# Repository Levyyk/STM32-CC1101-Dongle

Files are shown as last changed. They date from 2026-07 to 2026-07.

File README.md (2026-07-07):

# STM32 CC1101 USB Dongle

Custom USB dongle design featuring **STM32F030F4P6** + **CC1101** RF transceiver + **CH340N** USB-UART bridge.
A complete schematic and PCB design project built in Altium Designer — from component selection to a production-ready layout.

> **Note:** This is a design-stage project — the board has not been manufactured/assembled. The repository showcases the schematic and PCB design process rather than a physical build or firmware implementation.

| Front (3D) | Back (3D) |
|---|---|
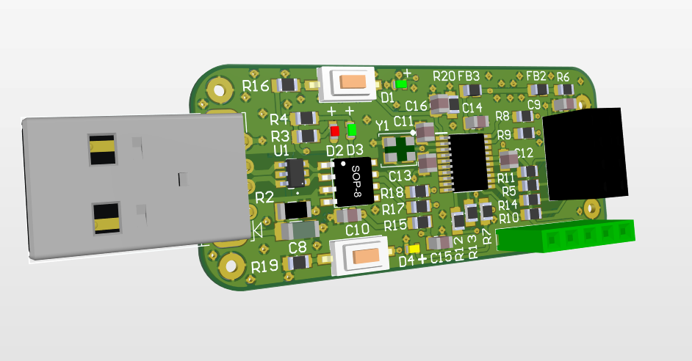
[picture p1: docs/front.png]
Board front
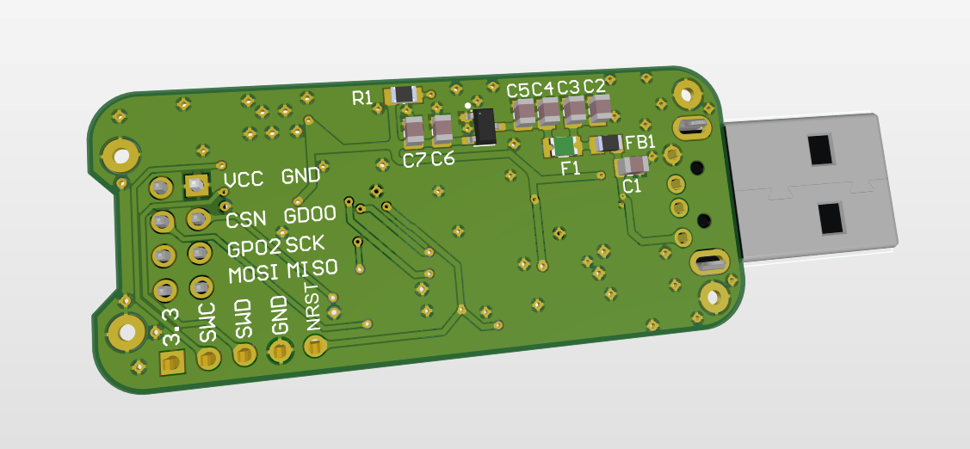
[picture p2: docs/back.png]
Board back
|  |  |

---

## Overview

This project is a compact USB dongle designed for interfacing with sub-GHz RF devices via the CC1101 transceiver. The STM32F030F4P6 is intended to handle SPI communication with the CC1101 and expose data to a host PC through a CH340N USB-to-UART bridge.

**Core components:**
| Component | Role |
|---|---|
| STM32F030F4P6 | Main MCU (Cortex-M0), SPI ↔ CC1101 and UART ↔ CH340N |
| CC1101 | Sub-GHz RF transceiver (315/433/868/915 MHz) |
| CH340N | USB-to-UART bridge for host communication |

---

## Block Diagram

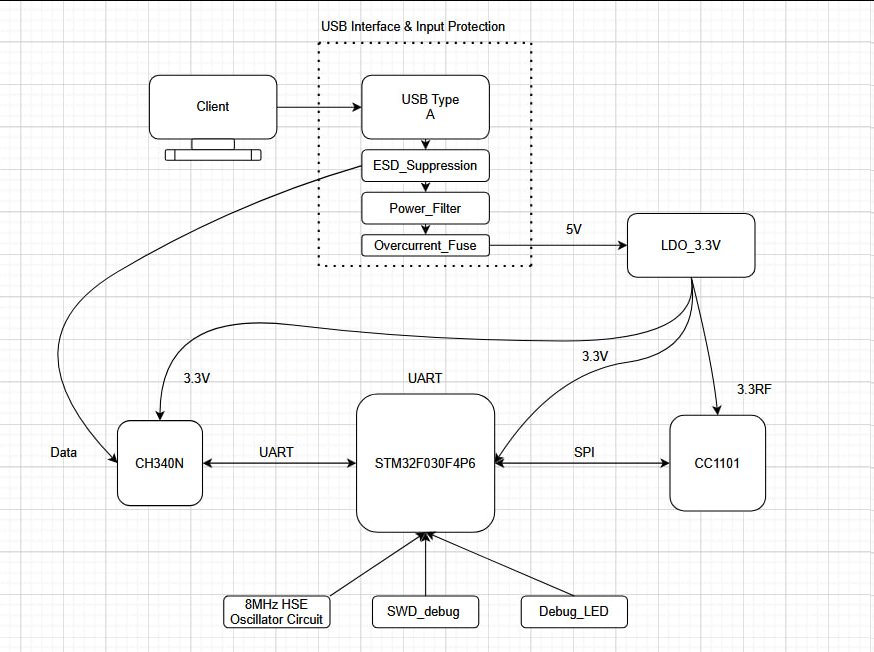
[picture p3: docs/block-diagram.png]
Block diagram


The system is structured around three functional zones:

- **USB Interface & Input Protection** — USB Type-A input passes through ESD suppression, power filtering, and an overcurrent fuse before being regulated down to 3.3V by an LDO. This isolates the rest of the board from transients and faults on the USB line.
- **Data path** — CH340N bridges USB data to a UART link with the STM32F030F4P6, which in turn communicates with the CC1101 RF transceiver over SPI.
- **Support circuitry** — an 8 MHz HSE oscillator provides a stable clock reference for the MCU, alongside a dedicated SWD debug header and a debug LED for development and troubleshooting.

---

## RF Module Reference — CC1101

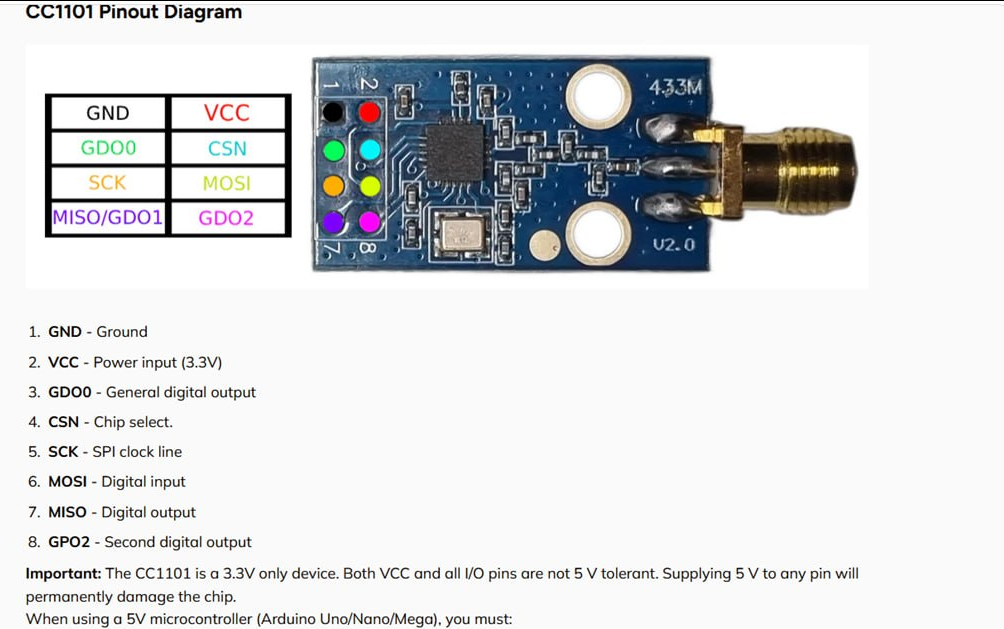
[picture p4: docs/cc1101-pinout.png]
CC1101 pinout


The CC1101 is a sub-GHz RF transceiver operating at **3.3V only** — VCC and all I/O pins are **not 5V tolerant**, which was a key constraint driving the power rail design (dedicated 3.3RF supply, see Block Diagram above).

## Schematic & PCB Design (Altium Designer)

All schematic and PCB design was done in **Altium Designer**.

- **Custom schematic symbol for CC1101** — no ready-made symbol was available in the standard libraries, so the component symbol and footprint were built and verified from the datasheet pinout.
- **Series resistors on SPI and UART lines** — added to dampen reflections and reduce EMI on high-speed digital lines between the MCU, CC1101, and CH340N.
- **USB protection** — a polyfuse (overcurrent protection) combined with a TVS diode (ESD/transient protection) on the USB data and power lines.
- **SWD header** — dedicated programming/debug interface for flashing and debugging via ST-Link.
- **PCB stack-up considerations** — evaluated Core vs. Prepreg material choices and controlled impedance requirements for the RF-adjacent traces near the CC1101.

**Schematic (PDF):**
[📄 docs/schematic.pdf](docs/schematic.pdf)

**PCB layers:**
| Top layer | Bottom layer |
|---|---|
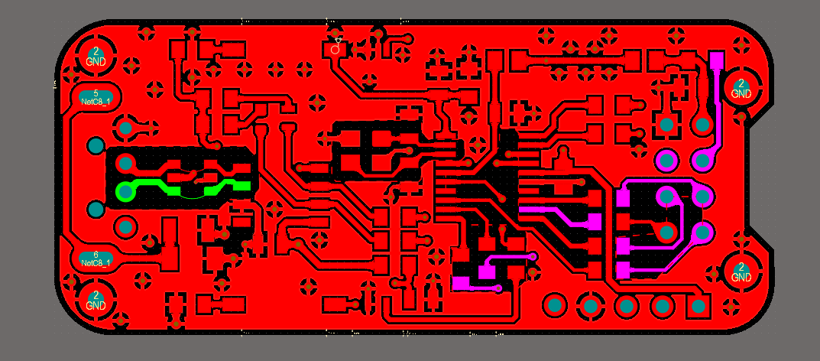
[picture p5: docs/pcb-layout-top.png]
Top layer
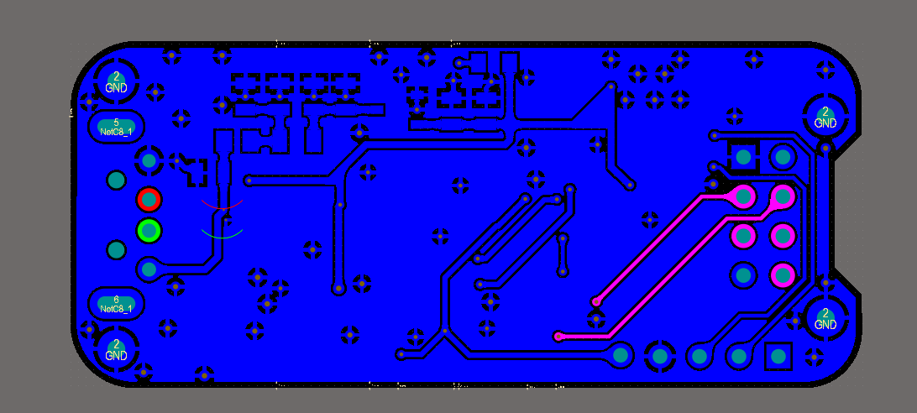
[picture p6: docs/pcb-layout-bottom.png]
Bottom layer
|  |  |

**Board dimensions:**
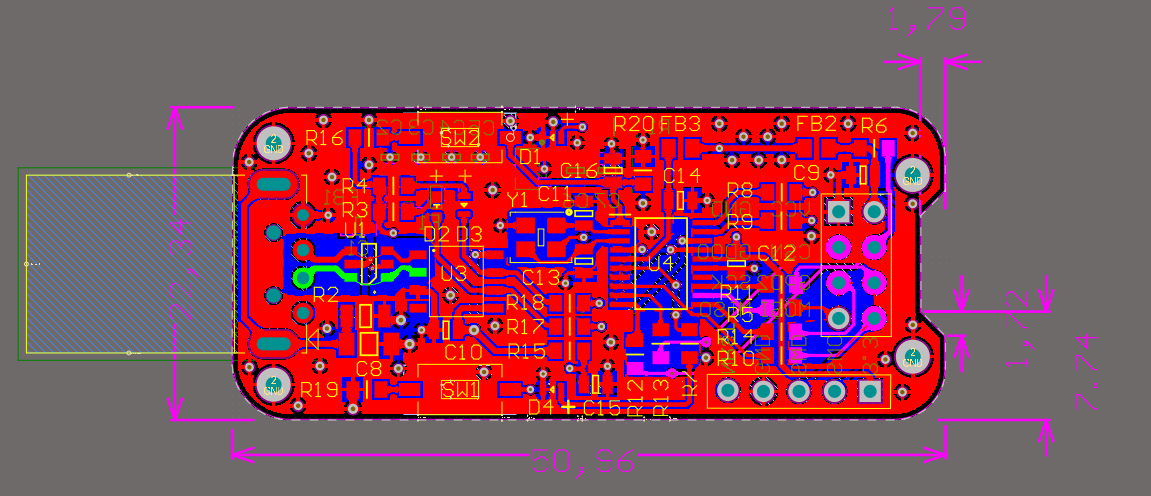
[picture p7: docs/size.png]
Board size


---

## Programming

The board is designed to be flashed and debugged via **SWD** using an **ST-LINK/V2** programmer.

🔗 [ST-LINK/V2 — official product page (STMicroelectronics)](https://www.st.com/en/development-tools/st-link-v2.html)

---

## Design Challenges & Solutions

Some of the practical considerations addressed during the design process:

- **USB input protection chain** — the USB line goes through ESD suppression, power filtering, and an overcurrent fuse before reaching the LDO. This layered approach was chosen so that transient/ESD events and fault conditions are caught as close to the USB connector as possible, before they can propagate to the 3.3V rail or the rest of the board.
- **Power regulation** — a dedicated LDO_3.3V converts the incoming 5V USB rail to a clean 3.3V supply for the STM32F030F4P6, CH340N, and CC1101, keeping digital and RF supply noise under control. This was also a hard requirement given the CC1101 is 3.3V-only and not 5V tolerant on any pin.
- **Signal integrity on SPI/UART lines** — added series termination resistors to dampen reflections/noise on high-speed digital lines between MCU and peripherals.
- **PCB material selection** — weighed Core vs. Prepreg options for the stack-up, considering controlled impedance requirements for RF-sensitive routing near the CC1101 (3.3RF supply and SPI lines).
- **Clock reference** — an 8 MHz HSE oscillator circuit was added for a stable, accurate clock source to the MCU, rather than relying solely on the internal RC oscillator.
- **Debug/development support** — a dedicated SWD_debug header and a Debug_LED were included on the board to simplify bring-up, flashing, and troubleshooting via ST-Link.

---

## What I'd Improve Next

- **Add test points** on key signal lines (SPI, UART, power rails) to make future debugging and validation easier without probing fine-pitch pins.
- **Formalize impedance calculations** for the RF-adjacent traces near the CC1101, rather than relying on general stack-up guidelines, to have documented confidence in the design.

---

## Skills Demonstrated

- Schematic capture & PCB design in Altium Designer (including custom library parts)
- Signal integrity considerations for high-speed digital and RF-adjacent traces
- USB interface protection design (ESD/overcurrent)
- PCB stack-up and material selection for controlled impedance
- SWD debug interface design

---

## Author

**Levyk** — Telecommunications & Radio Engineering student, Lviv Polytechnic National University
[GitHub](https://github.com/levyyk) ·

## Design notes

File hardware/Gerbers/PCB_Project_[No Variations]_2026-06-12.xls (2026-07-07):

Board Stack Report
Stack Up |  | Layer Stack
Layer | Board Layer Stack | Name | Material | Thickness | Constant
1 |  | Top Overlay |  | 0mm
2 |  | Top Solder | Solder Resist | 0.01016mm | 3.5
3 |  | Top Layer |  | 0.03556mm
4 |  | Dielectric 1 | FR-4 | 0.7mm | 4.5
5 |  | Bottom Layer |  | 0.03556mm
6 |  | Bottom Solder | Solder Resist | 0.01016mm | 3.5
7 |  | Bottom Overlay |  | 0mm
 | Height : 0.79144mm

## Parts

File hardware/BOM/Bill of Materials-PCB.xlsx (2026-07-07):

Quantity | Designator | Description | Manufacturer Part Number | Footprint | Manufacturer | Name | Populate | Buy | JLCPCB Part #
1 | C1 | 10nF 50V X7R ±10% 0805 Multilayer Ceramic Capacitors MLCC - SMD/SMT ROHS | CL21B103KBANNNC | C_0805 | Samsung Electro-Mechanics | 10nF |  | https://jlcpcb.com/parts/componentSearch?searchTxt=CL21B103KBANNNC | C1710
9 | C2, C5, C6, C9, C10, C12, C14, C15, C16 | 100nF 50V X7R ±10% 0805 Multilayer Ceramic Capacitors MLCC - SMD/SMT ROHS | CC0805KRX7R9BB104 | C_0805 | YAGEO | 0.1 uF |  | https://jlcpcb.com/partdetail/YAGEO-CC0805KRX7R9BB104/C49678 | C49678
1 | C3 | 25V 4.7uF X5R ±10% 0805 Multilayer Ceramic Capacitors MLCC - SMD/SMT ROHS | CL21A475KAQNNNE | C_0805 | Samsung Electro-Mechanics | 4.7uF |  | https://jlcpcb.com/partdetail/2131-CL21A475KAQNNNE/C1779 | C1779
2 | C4, C7 | 10uF 25V X5R ±10% 0805 Multilayer Ceramic Capacitors MLCC - SMD/SMT ROHS | СL21A106KAYNNNE | C_0805 | Samsung Electro-Mechanics | 10uF |  | https://jlcpcb.com/partdetail/16532-CL21A106KAYNNNE/C15850 | C15850
1 | C8 | 10nF 1kV X7R ±10% 1206 Multilayer Ceramic Capacitors MLCC - SMD/SMT ROHS | CC1206KKX7RCBB103 | C_1206 | YAGEO | 10nF |  | https://jlcpcb.com/partdetail/YAGEO-CC1206KKX7RCBB103/C107192 | C15850
2 | C11, C13 | 18pF 50V NP0 ±5% 0805 Multilayer Ceramic Capacitors MLCC - SMD/SMT ROHS | CC0805JRNPO9BN180 | C_0805 | YAGEO | 18pF |  | https://jlcpcb.com/partdetail/YAGEO-CC0805JRNPO9BN180/C113825 | C113825
2 | D1, D3 | -40℃~+85℃ 100mW 120° 3.1V 430mcd 513nm~528nm 525nm 5mA Discrete Diode Emerald Green Water Clear 0603 LED Indication - Discrete ROHS | KT-0603G | D_LED_SMD_0603_GREEN | Hubei KENTO Elec | KT-0603G |  | https://jlcpcb.com/partdetail/Hubei_KENTOElec-KT0603G/C12624 | C12624
1 | D2 | -40℃~+85℃ 1.8V~2.4V 120° 20mA 300mcd 40mW 615nm~630nm 645nm Discrete Diode Red Water Clear 0603 LED Indication - Discrete ROHS | KT-0603R | D_LED_SMD_0603_RED | Hubei KENTO Elec KT-0603R | KT-0603R |  | https://www.lcsc.com/product-detail/C2286.html?s_z=n_q_KT-0603R | C2286
1 | D4 | -40℃~+85℃ 120° 175mcd 2.4V 40mW 584nm~594nm 596nm Discrete Diode Water Clear Yellow 0603 LED Indication - Discrete ROHS | KT-0603Y | D_LED_SMD_0603_YELLOW | Hubei KENTO Elec | KT-0603Y |  | https://jlcpcb.com/partdetail/Hubei_KENTOElec-KT0603Y/C2287 | C2287
1 | F1 | -40℃~+85℃ 100A 150mΩ 16V 1A 500mA 500mW 850mΩ 8s 0805 Resettable Fuses ROHS | SMD0805-050-16V | F_0805 | TECHFUSE | SMD0805-050-16V |  | https://jlcpcb.com/partdetail/TECHFUSE-SMD0805_05016V/C2833485 | C2833485
1 | FB1 | 220Ω@100MHz 2A 45mΩ ±25% 0805 Ferrite Beads ROHS | BLM21PG601SN1D | FB_0805 | Murata Electronics | BLM21PG601SN1D |  | https://jlcpcb.com/partdetail/MurataElectronics-BLM21PG221SN1D/C85840 | C85840
2 | FB2, FB3 | FERRITE BEAD SMD 0805INCH 600OHM | BLM21PG601SN1D | FB_0805 | Murata Electronics | BLM21PG601SN1D |  | https://jlcpcb.com/partdetail/MurataElectronics-BLM21PG601SN1D/C41556732, https://www.digikey.com/en/products/detail/murata-electronics/BLM21PG601SN1D/24763118 | C41556732, [NoParam]
1 | J1 | Female Header 8 Position 2.54mm Pitch Dual Row Through Hole | DS1023-2*4SF11 | СС1101_Header 4X2 | CONNFLY Elec | DS1023-2*4SF11 |  | https://www.lcsc.com/product-detail/C92271.html?s_z=n_q_p_2.54mm%25202x4%2520Pin%2520Header | C92271
1 | J2 | -55℃~+105℃ 1 1x5P 2.54mm 3.2mm 3A 5P 8.5mm Brass Gold Square Hole Through Hole Top 插件,P=2.54mm Female Headers ROHS | 2.54-1*5PFemale | SWD_Header_Connector_5pos_Female | BOOMELE(Boom Precision Elec) | BOOMELE(Boom Precision Elec) |  | https://jlcpcb.com/partdetail/51962-2_54_15PFemale/C50950 | C50950
1 | P1 | USB-A (USB TYPE-A) USB 2.0 Plug Connector 4 Position Through Hole, Right Angle | 480370001 | USB-A (USB TYPE-A) | Molex | 480370001 |  | https://jlcpcb.com/partdetail/MOLEX-480370001/C136455 | C136455
4 | R1, R7, R16, R19 | -55℃~+155℃ 125mW 150V 220Ω Thick Film Resistor ±100ppm/℃ ±5% 0805 Chip Resistor - Surface Mount ROHS | RC0805JR-07220RL | Res_0805 | YAGEO | 220R |  | https://jlcpcb.com/partdetail/YAGEO-RC0805JR07220RL/C114742 | C114742
1 | R2 | -55℃~+155℃ 1MΩ 250mW 500V Thick Film Resistor ±1% ±100ppm/℃ 1206 Chip Resistor - Surface Mount ROHS | HV06W4F1004T5E | RES_1206 | UNI-ROYAL | 1M |  | https://jlcpcb.com/partdetail/406995-HV06W4F1004T5E/C414805 | C414805
2 | R3, R4 | -55℃~+155℃ 125mW 150V 1kΩ Thick Film Resistor ±1% ±100ppm/℃ 0805 Chip Resistor - Surface Mount ROHS | 0805W8F1001T5E | Res_0805 | UNI-ROYAL(Uniroyal Elec) | 1k |  | https://jlcpcb.com/partdetail/18201-0805W8F1001T5E/C17513 | C17513
4 | R5, R11, R12, R14 | -55℃~+155℃ 125mW 150V 47Ω Thick Film Resistor ±1% ±100ppm/℃ 0805 Chip Resistor - Surface Mount ROHS | 0805W8F470JT5E | Res_0805 | UNI-ROYAL(Uniroyal Elec) | 47R |  | https://jlcpcb.com/parts/componentSearch?searchTxt=0805%2047R%201%25 | C17714
3 | R6, R15, R20 | -55℃~+155℃ 10kΩ 125mW 150V Thick Film Resistor ±1% ±100ppm/℃ 0805 Chip Resistor - Surface Mount ROHS | 0805W8F1001T5E | Res_0805 | UNI-ROYAL(Uniroyal Elec) | 10k |  | https://jlcpcb.com/partdetail/18102-0805W8F1002T5E/C17414 | C17414
6 | R8, R9, R10, R13, R17, R18 | -55℃~+155℃ 100Ω 125mW 150V Thick Film Resistor ±1% ±100ppm/℃ 0805 Chip Resistor - Surface Mount ROHS | 0805W8F1000T5E | Res_0805 | UNI-ROYAL(Uniroyal Elec) | 100R |  | https://jlcpcb.com/partdetail/18096-0805W8F1000T5E/C17408 | C17414
2 | SW1, SW2 | Tactile Switch SPST 250gf 2.5mm Gull Wing 6.05mm x 3.6mm Surface Mount | TSA363G25-250B | SW_BRIGHT TSA363G25-250B | G-Switch | TSA363G25-250B |  | https://www.lcsc.com/product-detail/C354943.html | C354943
1 | U1 | -55℃~+125℃ 0.35pF、0.8pF 100nA 150W 15V 5V 6A 9V ESD IEC 61000-4-2、IEC 61000-4-5、IEC 61000-4-4 SOT-23-6 ESD and Surge Protection (TVS/ESD) ROHS | USBLC6-2SC6 | U_SOT23-6-292X160X125-95P-SGMICRO | TWGMC | USBLC6-2SC6 |  | https://jlcpcb.com/partdetail/TWGMC-USBLC62SC6/C5250994 | C5250994
1 | U2 | -40℃~+85℃@(Ta) 1 1uA 200mA 3.3V 6V Fixed Over Current Protection Positive SOT-23-3L Voltage Regulators - Linear, Low Drop Out (LDO) Regulators ROHS | XC6206P332MR-G | SOT-23_XC6206P332MR-G | Torex Semicon | XC6206P332MR-G |  | https://jlcpcb.com/partdetail/TorexSemicon-XC6206P332MRG/C5446 | C5446
1 | U3 | USB to serial 2Mbps USB 2.0 SOP-8 Interface Controllers RoHS |  | U_CH340N_SOP-8 |  | CH340N |  | https://jlcpcb.com/parts/componentSearch?searchTxt=C2977777 | C2977777
1 | U4 | 32-Bit MCU Cortex-M0 16KB Flash TSSOP20 STM32F030F4P6, 32 bit ARM Cortex M0 Microcontroller 48MHz 16 kB Flash, 4 kB RAM, I2C 20-Pin TSSOP |  | SOP65P640X120-20N |  | STM32F030F4P6 |  | https://jlcpcb.com/partdetail/STMicroelectronics-STM32F030F4P6/C32908 | C32908
1 | Y1 | -40℃~+85℃ 12pF 150Ω 8MHz Crystal Oscillator ±10ppm ±20ppm SMD3225-4P Crystals ROHS | X32258MOB4SI | SMD-3225 | YXC Crystal Oscillators | 8MHZ |  | https://jlcpcb.com/partdetail/2777872-X32258MOB4SI/C2682775 | C2682775

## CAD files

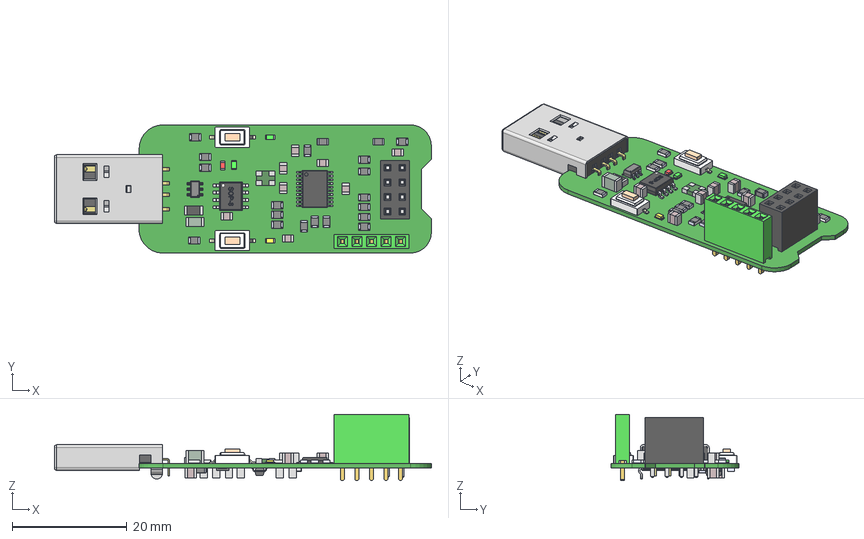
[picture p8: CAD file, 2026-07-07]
hardware/ExportSTEP/3DModel_PCB_Project.step
65.7 x 22.3 x 11.5 mm
RC0805FR-07976KL x 19
YSX321SL_YXC
ferrite_bead_0805 x 3
Extruded x 59
Pin001
Pin002
Pin003
Pin004
Pin005
Pin006
Pin007
Pin008
SOT-23_TOR
MAX4995BAUT+T
STM8S003F3P6
G73 button x 2
header_2.54_female_2x4pin
100mill Female Pin Header_5P_Gr
fuse_silicon_0805L

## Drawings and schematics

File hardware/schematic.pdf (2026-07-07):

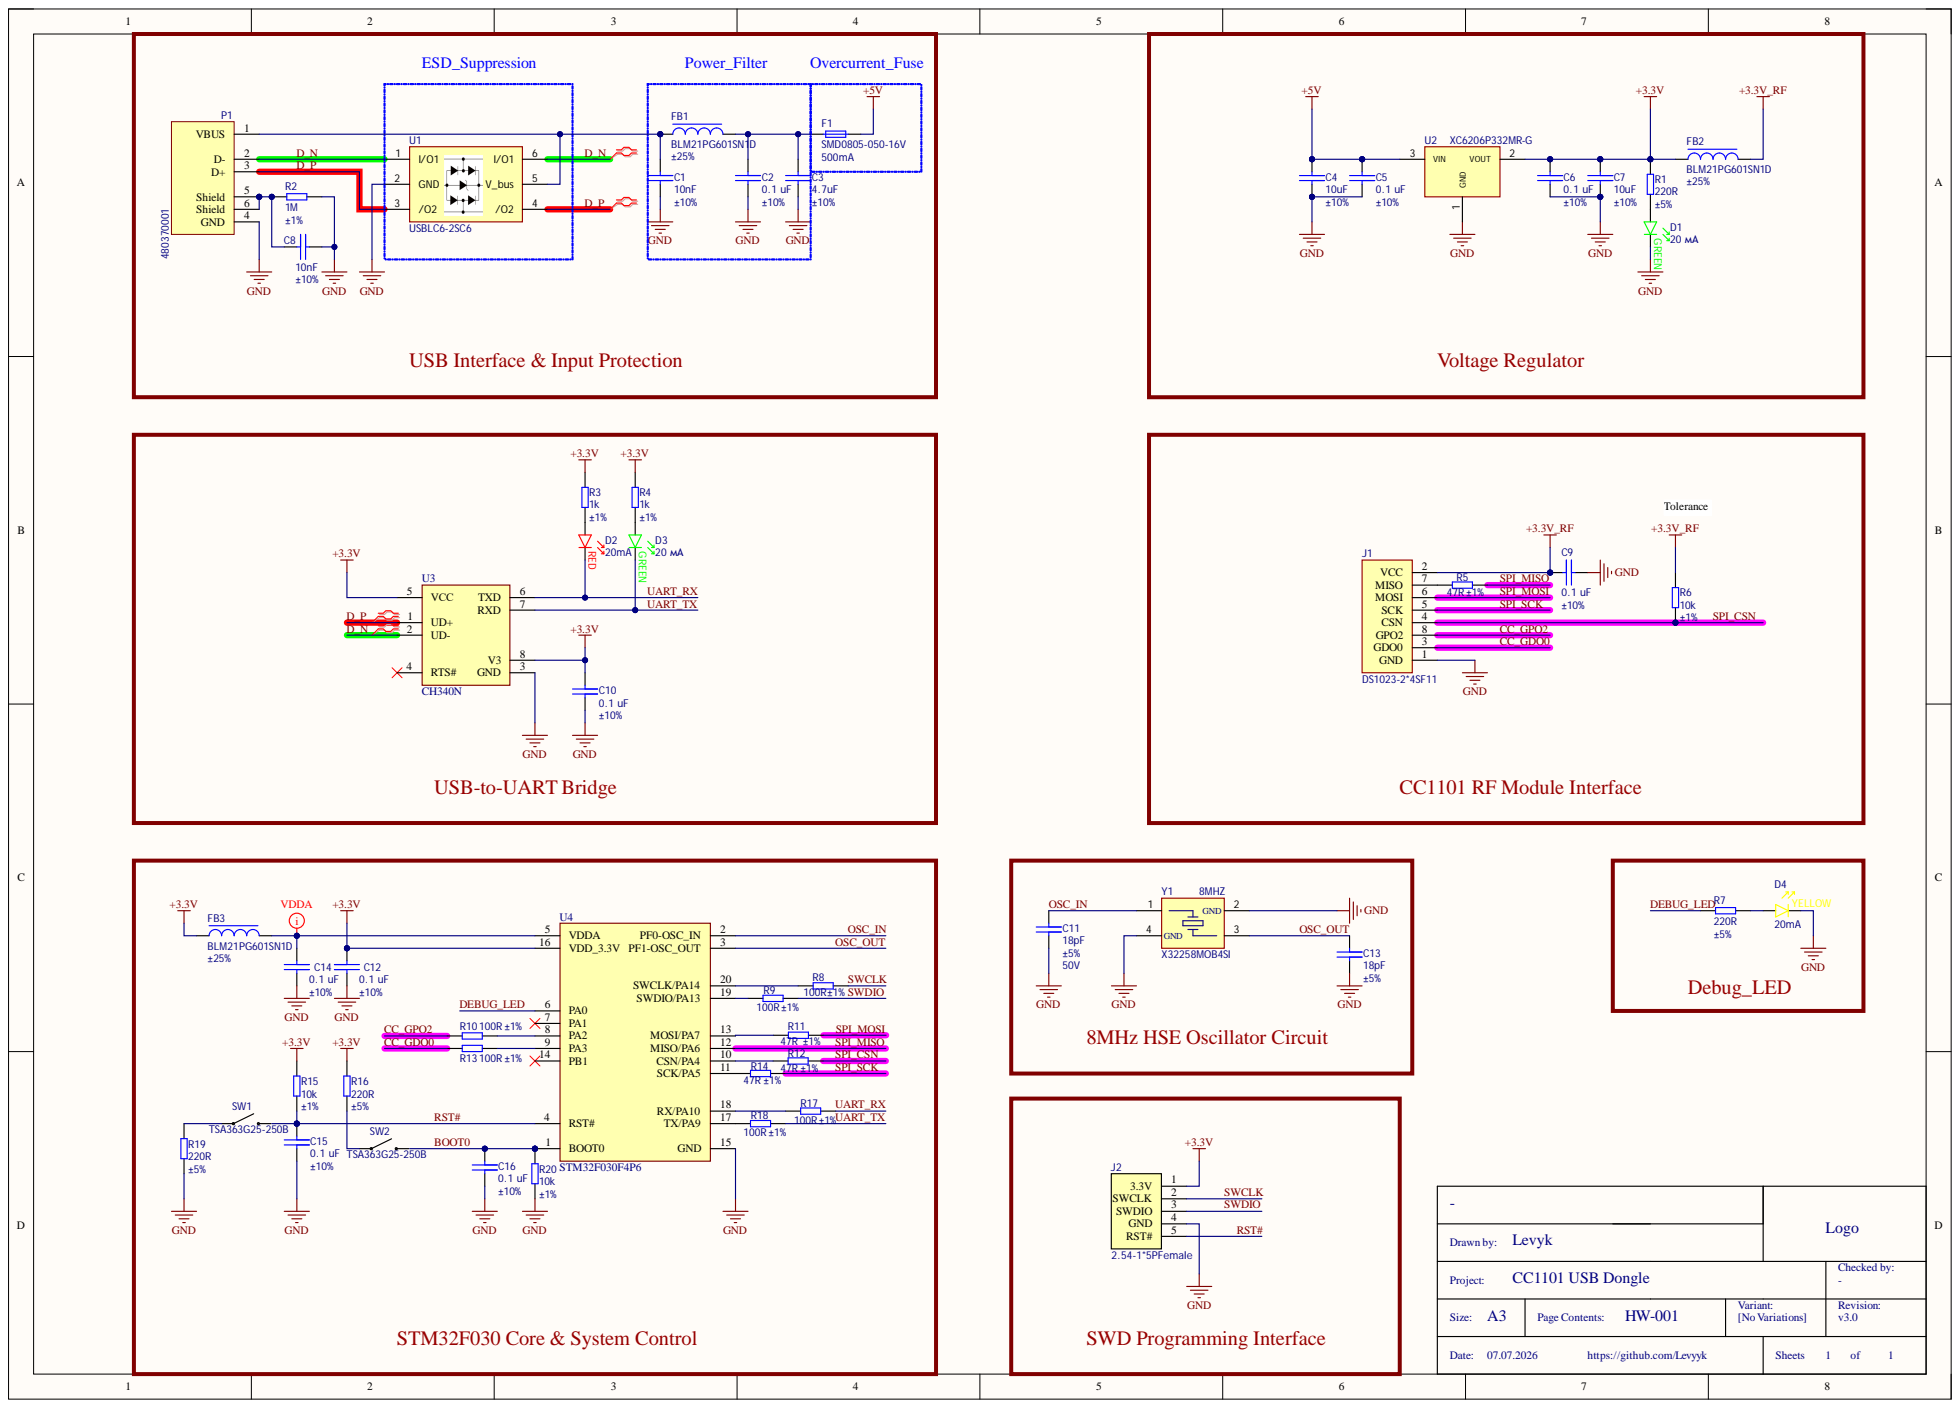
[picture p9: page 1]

USB Interface & Input Protection

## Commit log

2026-07-07 Revise README with detailed project information
    Updated project description, added overview, schematic, PCB design details, firmware information, design challenges, and skills demonstrated.
2026-07-07 Create Gerbers
2026-07-07 Add cc file to hardware Gerbers directory
2026-07-07 Add df file to BOM directory
2026-07-07 Rename PCB_Project_Lemberg_solutions_[No Variations]_2026-06-12-RoundHoles-NonPlated.TXT to PCB_Project__[No Variations]_2026-06-12-RoundHoles-NonPlated.TXT
2026-07-07 Rename PCB_Project_Lemberg_solutions_[No Variations]_2026-06-12-RoundHoles-Plated.TXT to PCB_Project_[No Variations]_2026-06-12-RoundHoles-Plated.TXT
2026-07-07 Rename PCB_Project__[No Variations]_2026-06-12-RoundHoles-NonPlated.TXT to PCB_Project_[No Variations]_2026-06-12-RoundHoles-NonPlated.TXT
2026-07-07 Rename PCB project file for consistency
2026-07-07 Rename PCB project Gerber file
    [PCB_Project_[No Variations]_2026-06-12.GTP]
2026-07-07 Rename PCB_Project_Lemberg_solutions_[No Variations]_2026-06-12.xls to PCB_Project_[No Variations]_2026-06-12.xls
    [PCB_Project_[No Variations]_2026-06-12.xls]
2026-07-07 Rename PCB_Project_Lemberg_solutions_[No Variations]_2026-06-12.GTS to PCB_Project_[No Variations]_2026-06-12.GTS
    [PCB_Project_[No Variations]_2026-06-12.GTS]
2026-07-07 Rename PCB_Project_Lemberg_solutions_[No Variations]_2026-06-12.GTO to PCB_Project_[No Variations]_2026-06-12.GTO
    [PCB_Project_[No Variations]_2026-06-12.GTO]
2026-07-07 Rename PCB_Project_Lemberg_solutions_[No Variations]_2026-06-12.GBO to PCB_Project_[No Variations]_2026-06-12.GBO
    [PCB_Project_[No Variations]_2026-06-12.GBO]
2026-07-07 Rename PCB_Project_Lemberg_solutions_[No Variations]_2026-06-12.LDP to PCB_Project_[No Variations]_2026-06-12.LDP
2026-07-07 Rename PCB_Project_Lemberg_solutions_[No Variations]_2026-06-12.GTL to PCB_Project_[No Variations]_2026-06-12.GTL
    [PCB_Project_[No Variations]_2026-06-12.GTL]
2026-07-07 Rename PCB_Project_Lemberg_solutions_[No Variations]_2026-06-12.GM1 to PCB_Project_[No Variations]_2026-06-12.GM1
    [PCB_Project_[No Variations]_2026-06-12.GM1]
2026-07-07 Rename PCB_Project_Lemberg_solutions_[No Variations]_2026-06-12.GBS to PCB_Project_[No Variations]_2026-06-12.GBS
    [PCB_Project_[No Variations]_2026-06-12.GBS]
2026-07-07 Rename PCB_Project_Lemberg_solutions_[No Variations]_2026-06-12.GBP to PCB_Project_[No Variations]_2026-06-12.GBP
    [PCB_Project_[No Variations]_2026-06-12.GBP]
2026-07-07 Rename PCB_Project_Lemberg_solutions_[No Variations]_2026-06-12.EXTREP to PCB_Project_[No Variations]_2026-06-12.EXTREP
2026-07-07 Rename PCB_Project_Lemberg_solutions_[No Variations]_2026-06-12-macro.APR_LIB to PCB_Project_[No Variations]_2026-06-12-macro.APR_LIB
2026-07-07 Rename PCB_Project_Lemberg_solutions_[No Variations]_2026-06-12.GM to PCB_Project_[No Variations]_2026-06-12.GM
2026-07-07 Rename PCB_Project_Lemberg_solutions_[No Variations]_2026-06-12-SlotHoles-Plated.TXT to PCB_Project_[No Variations]_2026-06-12-SlotHoles-Plated.TXT
2026-07-07 Rename PCB_Project_Lemberg_solutions_[No Variations]_2026-06-12.GBL to PCB_Project_[No Variations]_2026-06-12.GBL
    [PCB_Project_[No Variations]_2026-06-12.GBL]
2026-07-07 Rename PCB_Project_Lemberg_solutions_[No Variations]_2026-06-12.DRR to PCB_Project_[No Variations]_2026-06-12.DRR
2026-07-07 Rename PCB_Project_Lemberg_solutions_[No Variations]_2026-06-12.REP to PCB_Project_[No Variations]_2026-06-12.REP
